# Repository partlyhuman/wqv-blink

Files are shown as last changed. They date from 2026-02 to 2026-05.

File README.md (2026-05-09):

# WQV Blink
#### A Casio WQV Series USB Sync Dongle

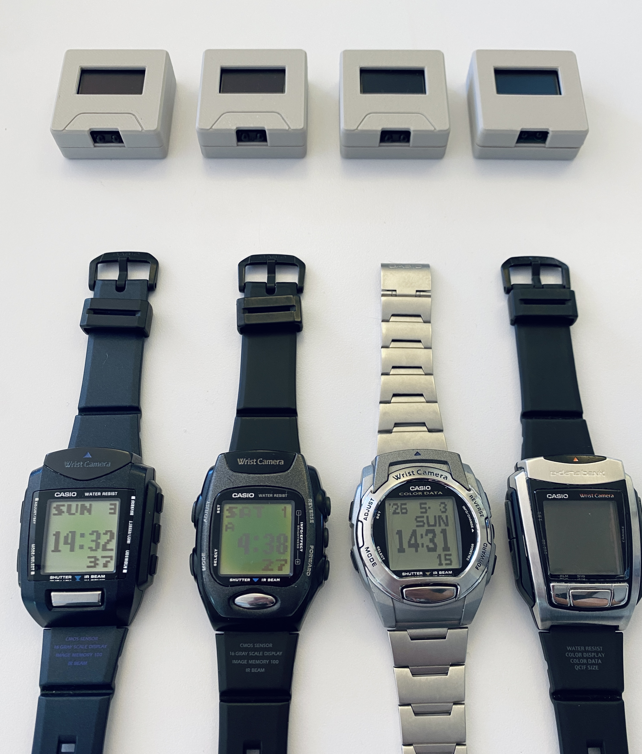
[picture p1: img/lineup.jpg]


This is an easy-to-use, self-contained device that retrieves photos from the series of extremely cool 2000-era [Casio WQV camera watches](https://www.casio.com/us/watches/50th/Heritage/2000s/) and stores them as a USB drive.

## Manual

See the [wiki](https://github.com/partlyhuman/wqv-blink/wiki) for all instructions!

## Purchase

Pre-assembled devices ars available in limited quantities on my [Ko-Fi shop](https://ko-fi.com/s/76fb4d3271)!

## Compatibility

Firmware [wqv12](firmware/wqv12):
* WQV-1 ✅
* WQV-2 ✅

Firmware [wqv310](firmware/wqv310):
* WQV-3 ✅
* WQV-10 ✅

## Building

The PCB, case, and firmware in this repository go together as pictured here. 

Gerbers are [included](pcb/WQV1-S3-SuperMini/production/). Fabricate with basic options, nothing fancy. 1.6mm thickness, HASL is just fine.

| Reference | Value | Details |
|----|----|----|
| R1 | 0-20R | 0805 Resistor |
| C1 | 1uF | 0805 Capacitor |
| C2 | 1uF | 0805 Capacitor |
| C3 | 0.1uF | 0805 Capacitor |
| U1 | ESP32-S3 Super Micro | https://www.aliexpress.com/item/1005007523988592.html |
| U2 | SSD1306_OLED_128x64 | https://www.aliexpress.com/item/1005006141235306.html (Yellow Blue) |
| U3 | TFDU4101-TR3 | https://www.digikey.com/short/nrdh27mb |

R1 is used to save power to the IR LED. The TFDU4101 has built-in LED resistors so this can be 0R for maximum TX power. There is a lot of good info on sample circuits and component values in the [TFDU4101 datasheet (PDF)](https://www.vishay.com/docs/81288/tfdu4101.pdf)

The [case](case/) is split into a top and bottom print. It can be printed with very basic settings. With the correct orientation, no supports are needed.

Builds are made with PlatformIO. In the firmware's directory, run `pio run -e esp32_s3_supermini` or use the PlatformIO VSCode extension. Note that this will not give you the dual-boot/dual-firmware option; for this, extra scripts are included. Alternatively, if you do not need to change anything, you can use the [web updater](https://wqv.partlyhuman.com/) to program the ESP32.

## DIY Build options



Breakouts are included to make a hand-wired device possible using breadboards, perfboards, jumpers, etc.

Currently this builds on ESP32-S2 and -S3 based boards. You can choose to include a common 0.96" monochrome SSD1306 screen or not based on the Platform.io environment.

Other ESP32 SoCs like the C3 lack the hardware to support USB Device mode, which we use to mount as a USB drive. See the [Espressif USB peripheral FAQ](https://docs.espressif.com/projects/esp-faq/en/latest/software-framework/peripherals/usb.html).

PSRAM is used if found on your board, but is not required. Flash space large enough to store 99 images (<1MB) as well as the program is required, should not be an issue.



A [Vishay TFDU4101](https://www.vishay.com/en/product/81288/) is the only required external component, used for bidirectional IRDA communication with the watch. It is still in production and widely available for cheap! In this repository you will find breakout PCBs that will give it 2.54mm standard header pins, [one barebones](pcb/TFDU4101-breakout/), and a more [user-friendly one](pcb/TFDU4101-breakout-simplified/) which includes the passive components, and a solder bridge to optionally power the IR LED & logic from a single supply (recommended, up to +6V is acceptable according to the datasheet). The silkscreen gives two possible orientations of the TFDU4101 so you can choose to aim it upwards or outwards. Double-check pin 1 to make sure your orientation is correct.

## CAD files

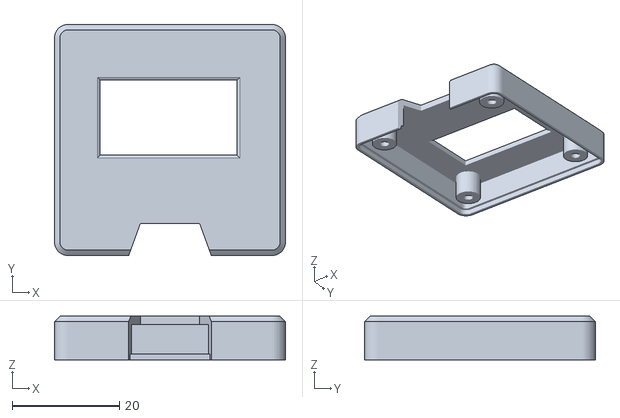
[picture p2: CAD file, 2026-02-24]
case/Case_WQV-1 IR Case Supermini v7_TOP.stl
43.0 x 43.0 x 8.10

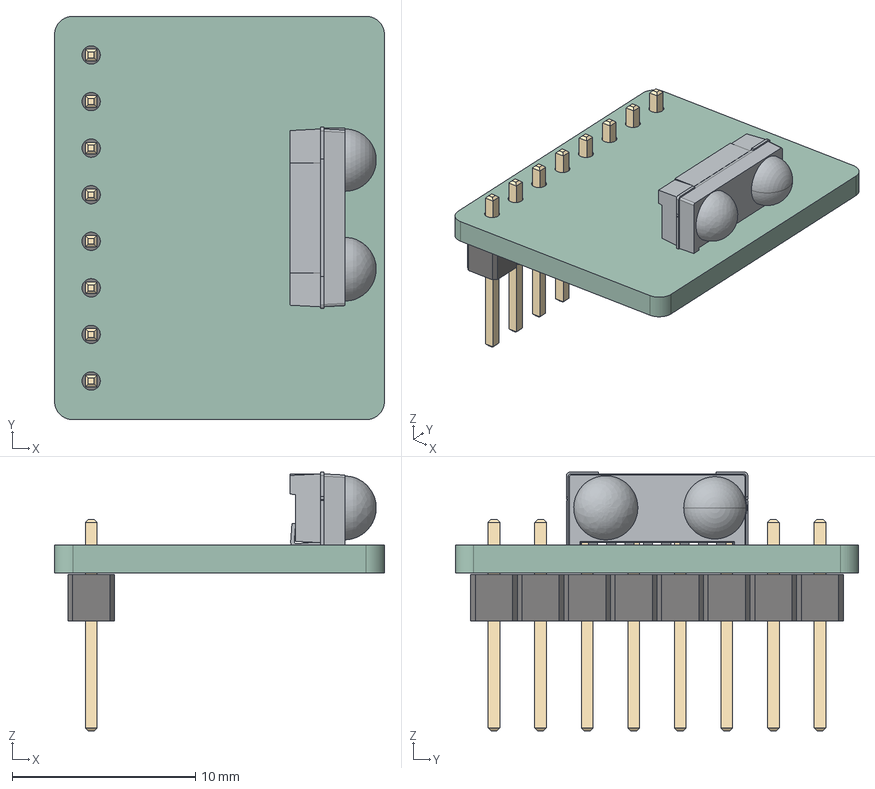
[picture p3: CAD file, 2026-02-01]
pcb/TFDU4101-breakout/TFDU4101-breakout.step
18.0 x 22.0 x 14.1 mm
TFDU4101
PinHeader_1x08_P2.54mm_Vertical
TFDU4101-breakout_PCB

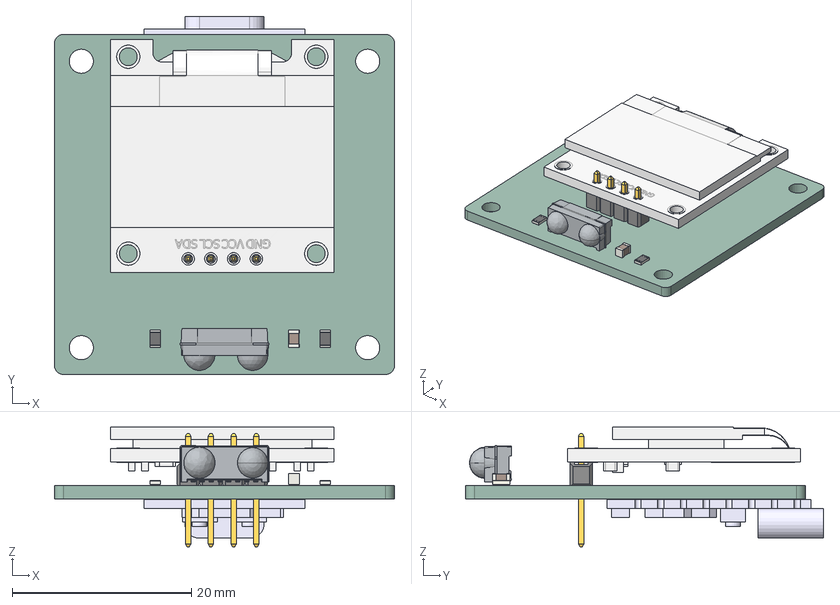
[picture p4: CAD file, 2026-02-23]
pcb/WQV1-S3-SuperMini/WQV1-S3-SuperMini.step
38.0 x 40.0 x 13.4 mm
OSSD-128x64
brep_1
brep_2
brep_3
brep_4
C_0805_2012Metric
R_0805_2012Metric x 2
TFDU4101
esp32c3supermini
WQV1-S3-SuperMini_PCB

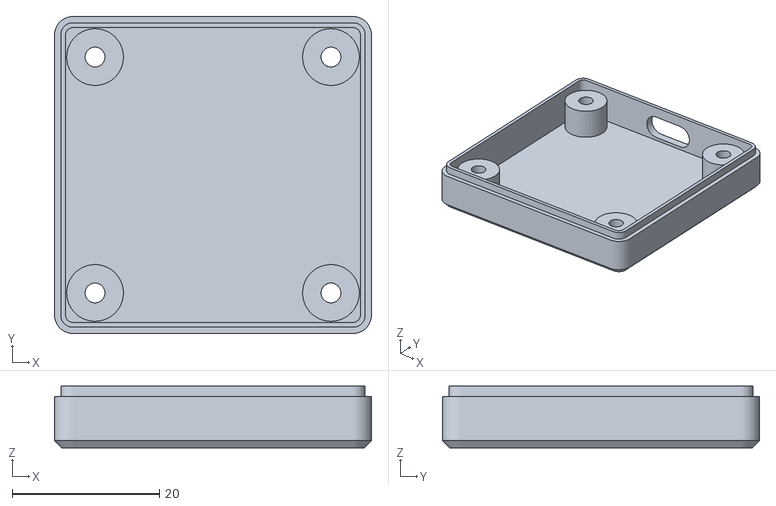
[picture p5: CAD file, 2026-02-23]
case/Case_WQV-1 IR Case Supermini v7_BOTTOM.stl
43.0 x 43.0 x 8.40

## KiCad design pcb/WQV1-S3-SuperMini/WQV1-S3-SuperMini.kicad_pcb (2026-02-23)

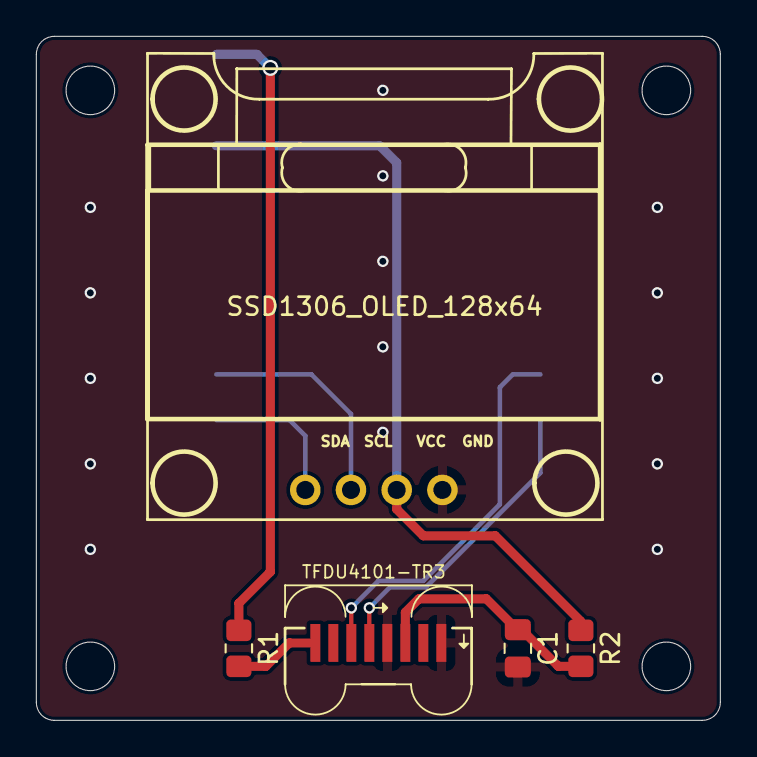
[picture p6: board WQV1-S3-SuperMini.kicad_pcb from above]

Board: 2 copper layers, 38.0 x 38.0 mm, 10 parts (1 on the bottom side), 9 nets.

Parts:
C1: 4.7u; C_0805_2012Metric_Pad1.18x1.45mm_HandSolder
H1, H2, H3, H4: MountingHole; MountingHole_2.7mm_M2.5
R1: 0R; R_0805_2012Metric_Pad1.20x1.40mm_HandSolder
R2: 47R; R_0805_2012Metric_Pad1.20x1.40mm_HandSolder
U1: ESP32-S3 Supermini; ESP32-S3-SuperMicro_SMD
U2: SSD1306_OLED_128x64; SSD1306
U3: TFDU4101-TR3; TFDU4101 Positioning Guides

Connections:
/+3.3V: R2.1, U1.16 (3V3), U2.2 (VCC)
/+5V: R1.1, U1.18 (5V)
/GND: C1.2, U1.17 (GND), U2.1 (GND), U3.5 (SD), U3.8 (GND)
/IRDA_RX: U1.9 (GP7), U3.4 (RXD)
/IRDA_TX: U1.8 (GP6), U3.3 (TXD)
/SCL: U1.11 (GP9), U2.3 (SCL)
/SDA: U1.10 (GP8), U2.4 (SDA)
unnamed: R1.2, U3.1 (IREDANODE)
unnamed: C1.1, R2.2, U3.6 (VCC1)

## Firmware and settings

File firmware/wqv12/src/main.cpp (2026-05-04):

/**
 * Implementation of WQV-1 protocol by @partlyhuman
 * Based on reverse engineering by https://www.mgroeber.de/wqvprot.html
 */
#include <FFat.h>

#include "config.h"
#include "display.h"
#include "firmware.h"
#include "frame.h"
#include "image.h"
#include "irda_hal.h"
#include "log.h"
#include "msc.h"

#ifdef ENABLE_PSRAM
#include "PSRamFS.h"
#endif

static const char *TAG = "Main";
static const char *DUMP_PATH = "/dump.bin";

const size_t ABORT_AFTER_RETRIES = 10;
const size_t MAX_IMAGES = 100;
// Packets seem to be up to 192 bytes
const size_t BUFFER_SIZE = 256;
static uint8_t readBuffer[BUFFER_SIZE]{};
// Transmission buffer and state variables
static uint8_t sessionId = 0xff;
static size_t len;
static size_t dataLen;
static uint8_t addr;
static uint8_t ctrl;
// Whether we're streaming the transferred data into PSRAM or FAT
static bool usePsram;

volatile static bool buttonPressed;
void IRAM_ATTR onButtonPress() {
    buttonPressed = true;
}

void setup() {
    Firmware::init();
    Display::init();
    Display::showBootScreen();

    Serial.begin(115200);

    pinMode(PIN_LED, OUTPUT);
    digitalWrite(PIN_LED, LED_OFF);

    // Should be a little under 1mb. PSRamFS will use heap if not available, we want to prevent that though
    usePsram = false;
#ifdef ENABLE_PSRAM
    size_t psramSize = MAX_IMAGES * sizeof(Image::Image) + 1024;
    if (psramInit() && psramSize < ESP.getMaxAllocPsram() && psramSize < ESP.getFreePsram()) {
        usePsram = PSRamFS.setPartitionSize(psramSize) && PSRamFS.begin(true);
    }
#endif
    LOGD(TAG, "Using %s for temp storage", usePsram ? "PSRAM" : "FFAT");

    MassStorage::init();
    Image::init();

    // Button manually toggles between Sync/USB (IR/MSC) mode and switches firmwares
    pinMode(PIN_BUTTON, INPUT_PULLUP);
    attachInterrupt(PIN_BUTTON, onButtonPress, FALLING);

#ifdef PIN_IRDA_SD
    // TFDU4101 Shutdown pin, powered by bus power, safe to tie to ground
    pinMode(PIN_IRDA_SD, OUTPUT);
    digitalWrite(PIN_IRDA_SD, LOW);
    delay(1);
#endif

    IRDA_setup(IRDA);
    while (!IRDA);

    LOGI(TAG, "Setup complete");
    delay(2500);
    buttonPressed = false;  // ignore any button presses during boot
}

/**
 * Small helper to validate that a received frame has the expected properties (the addr & control fields).
 * Checking the length of the data is optional. Checking the contents of the data is out of scope.
 */
static inline bool expect(uint8_t expectedAddr, uint8_t expectedCtrl, int expectedMinLength = -1) {
    if (addr != expectedAddr) {
        LOGD(TAG, "Expected addr=%02x got addr=%02x\n", expectedAddr, addr);
        return false;
    }
    if (ctrl != expectedCtrl) {
        LOGD(TAG, "Expected ctrl=%02x got ctrl=%02x\n", expectedCtrl, ctrl);
        return false;
    }
    if (expectedMinLength >= 0 && len < expectedMinLength) {
        LOGD(TAG, "Expected at least %d bytes of data, got %d\n", expectedMinLength, len);
        return false;
    }
    return true;
}

/**
 * Attempt to send a frame (from this device to the watch) and receive a frame in response. Every send has a response.
 * Will not return true unless a VALID frame is received (checksum must match, etc.)
 * Postcondition: after this method returns true, the globals addr, ctrl will be set to received values; the global
 * readBuffer will contain the DATA field of the frame after unescaping etc, and the global dataLen will contain the
 * length of valid data in that buffer.
 */
bool sendRetry(uint8_t a, uint8_t c, const uint8_t *d = nullptr, size_t l = 0, int retries = 5) {
    for (int retry = 0; retry < retries; retry++) {
        // digitalWrite(PIN_LED, LED_OFF);
        Frame::writeFrame(a, c, d, l);
        // Important: don't do any heavy work here or you'll miss the beginning of the buffer
        // digitalWrite(PIN_LED, LED_ON);
        len = IRDA.readBytesUntil(Frame::FRAME_EOF, readBuffer, BUFFER_SIZE);

        if (len <= 0) {
            LOGW(TAG, "Timeout, retrying %d...", retry);
            continue;
        }
        if (len == BUFFER_SIZE) {
            LOGE(TAG, "Filled buffer up all the way, probably dropping content");
            return false;
        }

        if (!Frame::parseFrame(readBuffer, len, dataLen, addr, ctrl)) {
            LOGW(TAG, "Malformed, retrying %d...", retry);
            continue;
        }
        return true;
    }
    return false;
}

/**
 * The first phase of any IR sync is opening the session. Performs a handshake that determines the "address" or "session
 * id", and prepares the watch to receive commands.
 * The open session is different in that the watch will send some responses multiple times (in response to subsequent
 * commands) before continuing to acknowledge the next command.
 * We also exit early if there is no reply to the first "hello?" send. This allows the caller to decide how frequently
 * to poll for a watch being here.
 */
bool openSession() {
    Display::showIdleScreen();

    sessionId = 0xff;

    // Set artificially low timeout for connecting so we can retry it frequently for faster connection
    IRDA.setTimeout(200);
    // >	FFh	B3h	(possibly repeated)
    sendRetry(0xff, 0xb3, nullptr, 0, 1);
    // Frame::writeFrame(0xff, 0xb3);
    // if (!readFrame()) return false;
    // <	FFh	A3h	<hh> <mm> <ss> <ff>
    if (!expect(0xff, 0xa3, 4)) {
        return false;
    }

    // Restore default timeout of 1sec after initial searching
    IRDA.setTimeout(1000);
    Display::dim(false);

    // We don't use the returned time. Maybe a future implementation could... tell you if your watch's time needs to be
    // adjusted? Except this device doesn't know the correct time either.

    // Generate a random session ID. Should avoid any escaped codes. 0 seems fine but we disallow it anyway.
    // No actual need to ensure its uniqueness.
    sessionId = (rand() % 0x1a) + 1;
    // echo back data adding the session ID to the end <hh> <mm> <ss> <ff><assigned address>
    readBuffer[4] = sessionId;

    Display::showConnectingScreen(0);

    for (size_t i = 0;;) {
        // >	FFh	93h	<hh> <mm> <ss> <ff><assigned address>
        sendRetry(0xff, 0x93, readBuffer, 5, 1);
        // <	<adr>	63h	(possibly repeated)
        if (expect(sessionId, 0x63)) break;
        if (++i > ABORT_AFTER_RETRIES) return false;
    }

    Display::showConnectingScreen(1);

    for (size_t i = 0;;) {
        // >	<adr>	11h
        sendRetry(sessionId, 0x11);
        // <	<adr>	01h
        if (expect(sessionId, 0x01)) break;
        if (++i > ABORT_AFTER_RETRIES) return false;
    }

    Display::showConnectingScreen(2);

    LOGI(TAG, "Handshake complete, connection established!");
    return true;
}

/**
 * Once a "download all images" synchronization sequence has been established by downloadImages(), performs the
 * download.
 * The images are presented as a flat array of these packed Image structs. Individual frames can include bytes from two
 * contiguous Images, so we focus on getting all the bytes (into a "dump") and then processing them afterwards. The dump
 * is stored in a file as it may be quite large for memory. This method doesn't care where the file is, just sees a
 * stream.
 * The download is performed by a sequence of "request address", "respond address data" pairs.  The "address" here is
 * not the actual byte offset but two repeating sequences, which is sufficient to guarantee ordering. Mgroeber calls
 * this "pumping" data.
 */
bool downloadToFile(size_t imgCount, Stream &stream) {
    const size_t IMAGE_SIZE = sizeof(Image::Image);

    // fixed initial packet sequence IDs
    uint8_t getPacketNum = 0x31;
    uint8_t retPacketNum = 0x42;
    for (size_t position = 0, retries = 0; position < IMAGE_SIZE * imgCount;) {
        if (retries > ABORT_AFTER_RETRIES) {
            LOGE(TAG, "Aborting sync after %d retries", ABORT_AFTER_RETRIES);
            return false;
        }

        // >    <adr> <getPacketNum>
        if (!sendRetry(sessionId, getPacketNum, nullptr, 0, 1)) {
            retries++;
            continue;
        }
        // <    <adr> <retPacketNum> 05h <data...>
        if (!expect(sessionId, retPacketNum)) {
            LOGW(TAG, "Mismatched Send %02x expect ret %02x, retrying", getPacketNum, retPacketNum);
            retries++;
            continue;
        }
        if (readBuffer[0] != 0x5) {
            LOGW(TAG, "Expected data to start with 0x05, retrying");
            retries++;
            continue;
        }
        retries = 0;

        // Append to file, skipping the initial 0x05
        position += stream.write(readBuffer + 1, dataLen - 1);

        // increment packet ids
        getPacketNum = getPacketNum + 0x20;  // natural wraparound 0xF1 + 0x20 = 0x11
        retPacketNum += 0x2;
        if (retPacketNum >= 0x50) retPacketNum = 0x40;  // cycles 40-4E,40-4E...

        // int curImg = offset / IMAGE_SIZE;
        // LOGI(TAG, "Progress: image %d/%d\t| %d bytes\t| %0.0f%%", curImg + 1, imgCount, offset,
        //      100.0f * offset / imgCount / IMAGE_SIZE);
        Display::showProgressScreen(position, IMAGE_SIZE * imgCount, IMAGE_SIZE);
    }

    LOGI(TAG, "Done reading all images!");
    return true;
}

/**
 * Establishes a full download of all images on the watch. The actual downloading is performed by downloadToFile() to a
 * file that we prepare for it. This handshaking will determine how many images are going to be received.
 */
bool downloadImages() {
    // >	<adr>	10h	01h
    static const uint8_t args_1[]{0x1};
    IRDA.flush();
    sendRetry(sessionId, 0x10, args_1, sizeof(args_1));
    // <	<adr>	21h
    if (!expect(sessionId, 0x21)) return false;

    Display::showConnectingScreen(3);

    // >	<adr>	11h
    sendRetry(sessionId, 0x11);
    // <	<adr>	20h	07h FAh 1Ch 3Dh <num_images>
    if (!expect(sessionId, 0x20, 5)) return false;

    Display::showConnectingScreen(4);

    size_t imgCount = readBuffer[4];
    LOGI(TAG, "Watch says %d images available", imgCount);
    // >	<adr>	32h	06h
    static const uint8_t args_6[]{0x6};
    sendRetry(sessionId, 0x32, args_6, sizeof(args_6));
    // <	<adr>	41h
    if (!expect(sessionId, 0x41)) return false;

    Display::showConnectingScreen(5);

    LOGI(TAG, "Upload preamble completed!");

    // Start every session with a fresh disk,
    // but don't wipe until we are just about to save, in order to allow access to previous export
    FFat.end();
    FFat.format(false);
    FFat.begin();

    size_t size = imgCount * sizeof(Image::Image);
    File dump;
#ifdef ENABLE_PSRAM
    if (usePsram)
        dump = PSRamFS.open(DUMP_PATH, FILE_WRITE);
    else
#endif
        dump = FFat.open(DUMP_PATH, FILE_WRITE);

    if (!dump) {
        LOGE(TAG, "Failed to allocate file %d bytes", size);
        return false;
    }
    downloadToFile(imgCount, dump);
    dump.close();

    return true;
}

/**
 * After a successful download, cleanly disconnects from the watch. After this is performed, the watch goes back into
 * the IR menu.
 */
bool closeSession() {
    LOGI(TAG, "Closing session...");
    // >	<adr>	54h	06h
    static const uint8_t args_6[]{0x6};
    sendRetry(sessionId, 0x54, args_6, sizeof(args_6));

    // <	<adr>	61h
    // TODO observing a number of different responses (0x61, 0x43,...) in real world here
    // LOGD(TAG, "Close session reply to 0x54 is 0x%02x followed by %d bytes, expected 0x61 or 0x43", ctrl, dataLen);
    if (!(expect(sessionId, 0x43) || expect(sessionId, 0x61))) return false;

    // >	<adr>	53h
    sendRetry(sessionId, 0x53);
    // <	<adr>	63h
    if (!expect(sessionId, 0x63)) return false;

    LOGI(TAG, "Successful close session handshake. Disconnected.");
    sessionId = 0xff;
    return true;
}

void loop() {
    if (buttonPressed) {
        ulong startTime = millis();
        ulong holdTime = 0;
        while (digitalRead(PIN_BUTTON) == LOW) {
            holdTime = millis() - startTime;
            if (holdTime > 500) {
                Firmware::rebootIntoNextPartition();
                return;
            }
        }
        Display::dim(false);
        if (MassStorage::active) {
            MassStorage::end();
        } else {
            Display::showMountedScreen();
            MassStorage::begin();
        }
        buttonPressed = false;
        return;
    }

    if (MassStorage::active) {
        return;
    }

    // Needed to clear after errors
    Display::showIdleScreen();
    if (openSession()) {
        if (downloadImages()) {
            // Don't require a clean disconnect to continue
            closeSession();

            File dump;
#ifdef ENABLE_PSRAM
            if (usePsram)
                dump = PSRamFS.open(DUMP_PATH, FILE_READ);
            else
#endif
                dump = FFat.open(DUMP_PATH, FILE_READ);
            Image::exportImagesFromDump(dump);
            dump.close();
            delay(250);  // Give the 100% screen some time to register

            Display::showMountedScreen();
            Serial.println("\n\nAttaching mass storage device, go look for your images!");
            Serial.println("Don't forget to eject when done!");

            Serial.flush();
            MassStorage::active = true;
            MassStorage::begin();
            return;
        }
    }

    // LOGE(TAG, "Failure or no watch present, restarting from handshake");
    // delay(1000);
}

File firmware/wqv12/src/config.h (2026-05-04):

#pragma once

// Which UART to use IRDA on
#ifndef IRDA_UART_NUM
#define IRDA_UART_NUM 1
#endif

// Builtin LED
#ifndef PIN_LED
#define PIN_LED LED_BUILTIN
#endif

#define LED_ON HIGH
#define LED_OFF LOW

// Builtin button
#ifndef PIN_BUTTON
#define PIN_BUTTON 0
#endif

// Vishay TFDU4101
#ifndef PIN_IRDA_TX
#define PIN_IRDA_TX 10
#endif
#ifndef PIN_IRDA_RX
#define PIN_IRDA_RX 13
#endif

// I2C Display
#ifndef PIN_I2C_SDA
#define PIN_I2C_SDA SDA
#endif
#ifndef PIN_I2C_SCL
#define PIN_I2C_SCL SCL
#endif
#ifndef I2C_CLOCK
#define I2C_CLOCK 1000000UL
#endif

// RGB LED
#ifndef PIN_WS2812
#define PIN_WS2812 48
#endif

#define THIS_FIRMWARE_SLOT 0

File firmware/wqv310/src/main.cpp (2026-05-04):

#include <FFat.h>

#include <cstring>

#include "app.h"
#include "chunk.h"
#include "config.h"
#include "display.h"
#include "firmware.h"
#include "frame.h"
#include "image.h"
#include "irda_hal.h"
#include "log.h"
#include "msc.h"
#include "types.h"

// Temp debugging aid
#define LOGFAIL            \
    {                      \
        LOGE(TAG, "FAIL"); \
        Frame::log(frame); \
        return false;      \
    }

using namespace App;

static const char *TAG = "Main";

static const size_t ABORT_AFTER_RETRIES = 10;
static uint8_t ourPort = 0xff;
static uint8_t watchPort = 0xff;
static int model;
static uint8_t session;
// Shortcut to fill in the arg with the current session e.g. S(CMD_SET_TIME)
#define S(arg) App::fill((arg), session)

static Frame::Frame frame;

enum SequenceType {
    SEQ_ACK,
    SEQ_DATA,
};

static uint8_t seq_upper = 1, seq_lower = 0;

inline uint8_t seq(SequenceType type = SEQ_ACK, bool incUpper = false, bool incLower = false) {
    if (incUpper) seq_upper += 0x2;
    if (incLower) seq_lower += 0x2;
    return (seq_upper & 0xf) << 4 | ((type == SEQ_ACK ? 1 : seq_lower) & 0xf);
}

volatile static bool buttonPressed;
void IRAM_ATTR onButtonPress() {
    buttonPressed = true;
}

void setup() {
    Firmware::init();
    Display::init();
    Display::showBootScreen();

    Serial.begin(115200);

    pinMode(PIN_LED, OUTPUT);
    digitalWrite(PIN_LED, LED_OFF);

    Image::init();
    MassStorage::init();

    // Button manually toggles between Sync/USB (IR/MSC) mode or reboots into other firmware
    pinMode(PIN_BUTTON, INPUT_PULLUP);
    attachInterrupt(PIN_BUTTON, onButtonPress, FALLING);

#ifdef PIN_IRDA_SD
    // TFDU4101 Shutdown pin, powered by bus power, safe to tie to ground
    pinMode(PIN_IRDA_SD, OUTPUT);
    digitalWrite(PIN_IRDA_SD, LOW);
    delay(1);
#endif

    IRDA_setup(IRDA);
    while (!IRDA);

    LOGI(TAG, "Setup complete");
    delay(2500);
    buttonPressed = false;  // ignore any button presses during boot
}

/**
 * Small helper to validate that a received frame has the expected properties (the port & control fields).
 * Checking the length of the data is optional. Checking the contents of the data is out of scope.
 */
static bool expect(uint8_t expectedport, uint8_t expectedseq, int expectedMinLength = -1) {
    if (frame.error != Frame::FRAME_OK) {
        LOGW(TAG, "Frame not okay, status=%d", frame.error);
        return false;
    }
    if (frame.port != expectedport) {
        LOGE(TAG, "Expected port=%02x got port=%02x\n", expectedport, frame.port);
        return false;
    }
    if (frame.seq != expectedseq) {
        LOGE(TAG, "Expected seq=%02x got seq=%02x\n", expectedseq, frame.seq);
        return false;
    }
    if (expectedMinLength >= 0 && frame.data.size() < expectedMinLength) {
        LOGE(TAG, "Expected at least %d bytes of data, got %d\n", expectedMinLength, frame.data.size());
        return false;
    }
    return true;
}

static bool expectAck() {
    if (frame.error != Frame::FRAME_OK) {
        LOGE(TAG, "Frame not okay, status=%d", frame.error);
        return false;
    }
    if (frame.port != watchPort) {
        LOGE(TAG, "Expected port=%02x got port=%02x\n", watchPort, frame.port);
        return false;
    }
    if ((frame.seq & 0xF) != 1) {
        LOGE(TAG, "Expected seq=X1 (ACK) got seq=%02x\n", frame.seq);
        return false;
    }
    if (frame.data.size() > 0) {
        LOGE(TAG, "Expected empty data, got %d\n", frame.data.size());
        return false;
    }
    return true;
}

template <size_t N>
static bool expectStartsWith(const uint8_t (&cmp)[N]) {
    if (frame.error != Frame::FRAME_OK) LOGFAIL;
    bool ret = frame.data.size() >= N && std::equal(frame.data.begin(), frame.data.begin() + N, cmp);
    if (!ret) {
        LOGE(TAG, "Expected frame to start with:");
        for (auto b : cmp) Serial.printf("%02x ", b);
        Serial.println();
    }
    return ret;
}

static bool expectStartsWith(std::span<const uint8_t> cmp) {
    if (frame.error != Frame::FRAME_OK) LOGFAIL;
    bool ret = frame.data.size() >= cmp.size() && std::equal(cmp.begin(), cmp.end(), frame.data.begin());
    if (!ret) {
        LOGE(TAG, "Expected frame to start with:");
        for (auto b : cmp) Serial.printf("%02x ", b);
        Serial.println();
    }
    return ret;
}

static bool expectExactly(std::span<const uint8_t> cmp) {
    if (frame.error != Frame::FRAME_OK) LOGFAIL;
    bool ret = frame.data.size() == cmp.size() && std::equal(cmp.begin(), cmp.end(), frame.data.begin());
    if (!ret) {
        LOGE(TAG, "Expected frame to start with:");
        for (auto b : cmp) Serial.printf("%02x ", b);
        Serial.println();
    }
    return ret;
}

static bool expectAppPacketWithCommand(const char *expected) {
    if (!expectStartsWith(S(CLIENT_APP_PACKET))) return false;
    std::string actual = getCmdName(frame);
    if (actual != expected) {
        LOGE(TAG, "Expected command packet with cmd '%s', but received '%s'", expected, actual.c_str());
        return false;
    }
    return true;
}
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

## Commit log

2026-02-01 Find TFDU4101 model, fix origin in freecad, export model of breakout
    [TFDU4101-breakout.kicad_pcb, TFDU4101-breakout.step]
2026-02-07 Inverted status bar gfx
    [display_128x64.cpp]
2026-02-23 Add C3 supermini for rough placement
    [WQV1-S3-SuperMini.kicad_pcb, WQV1-S3-SuperMini.step]
2026-02-23 3d printed case
    [Case_WQV-1 IR Case Supermini v6_BOTTOM.stl, Case_WQV-1 IR Case Supermini v6_TOP.stl]
2026-02-24 Add BOM
2026-02-24 Restore larger screw posts
    [Case_WQV-1 IR Case Supermini v6_TOP.stl, Case_WQV-1 IR Case Supermini v7_BOTTOM.stl, Case_WQV-1 IR Case Supermini v7_TOP.stl]
2026-03-01 Fix MSC not using same LED pin, leaving light on
    [main.cpp, msc.cpp]
2026-03-15 Working irda serial device
2026-04-09 Fix Windows error on dismount by not rebooting when done, new file naming scheme
    [display_128x64.cpp, main.cpp, msc.cpp]
2026-04-30 Use PSRAM to avoid writing two files to flash, and speed up final copy
    [main.cpp]
2026-10-14 Loosen and deepen screw posts in case, kept breaking off in one filament
